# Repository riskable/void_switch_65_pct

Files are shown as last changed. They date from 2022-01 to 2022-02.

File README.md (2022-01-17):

# Void Switch Reference PCB Implementation

A reference implementation of an analog hall effect keyboard (65%) that uses 3D printed Void Switches and a Black Pill (STM32F4x1CEU6) microcontroller board.

__WARNING:__ I haven't had a chance to order and test this yet!  Use at your own risk!  YOU HAVE BEEN WARNED!

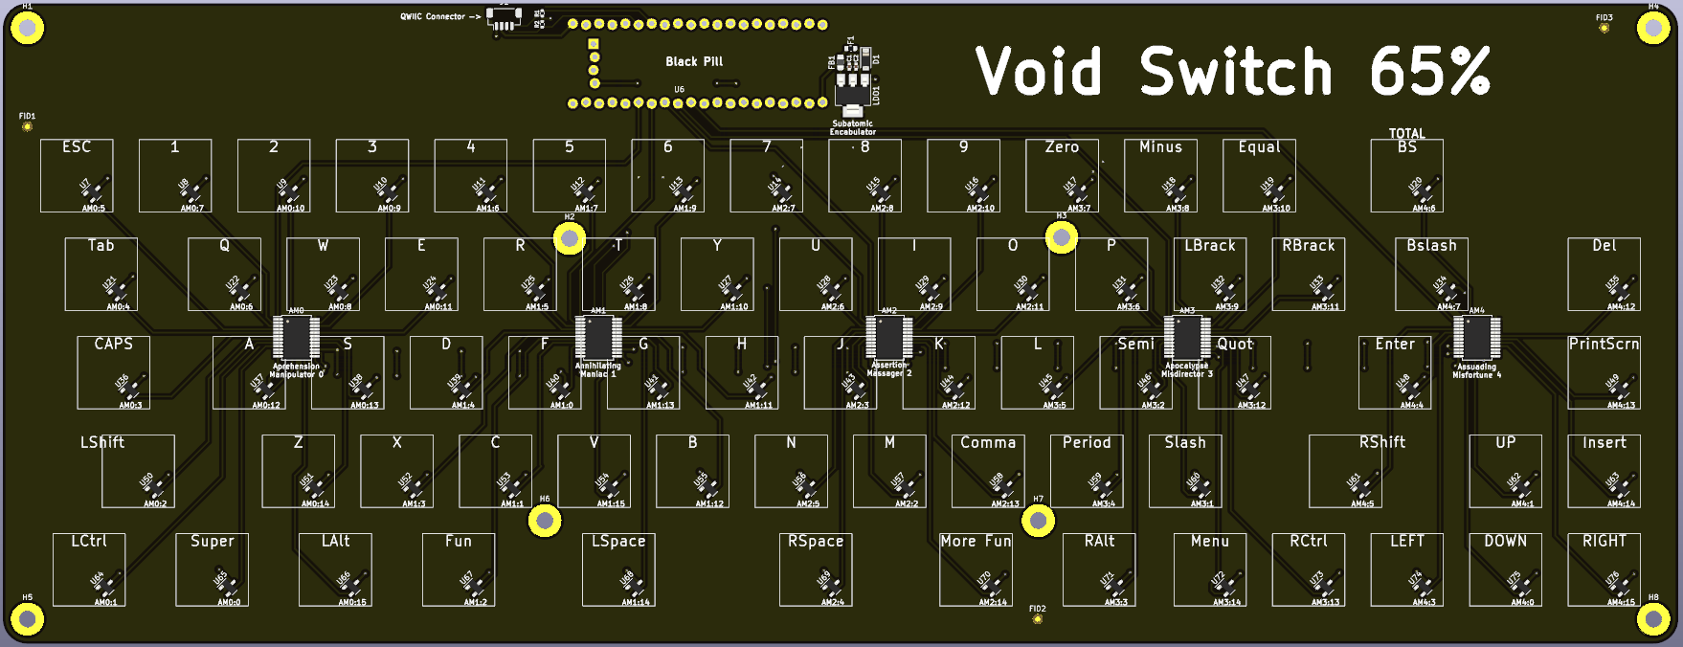
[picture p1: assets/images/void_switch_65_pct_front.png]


Inside this repository is a Kicad 6 project that has everything you need to get started making an analog keyboard PCB that uses 3D printed [Void Switches](https://github.com/riskable/void_switch).  It was made as part of a tutorial that is currently being worked on.  In the mean time--if you know what you're doing--feel to use it as a reference for creating your own analog keyboard PCBs.

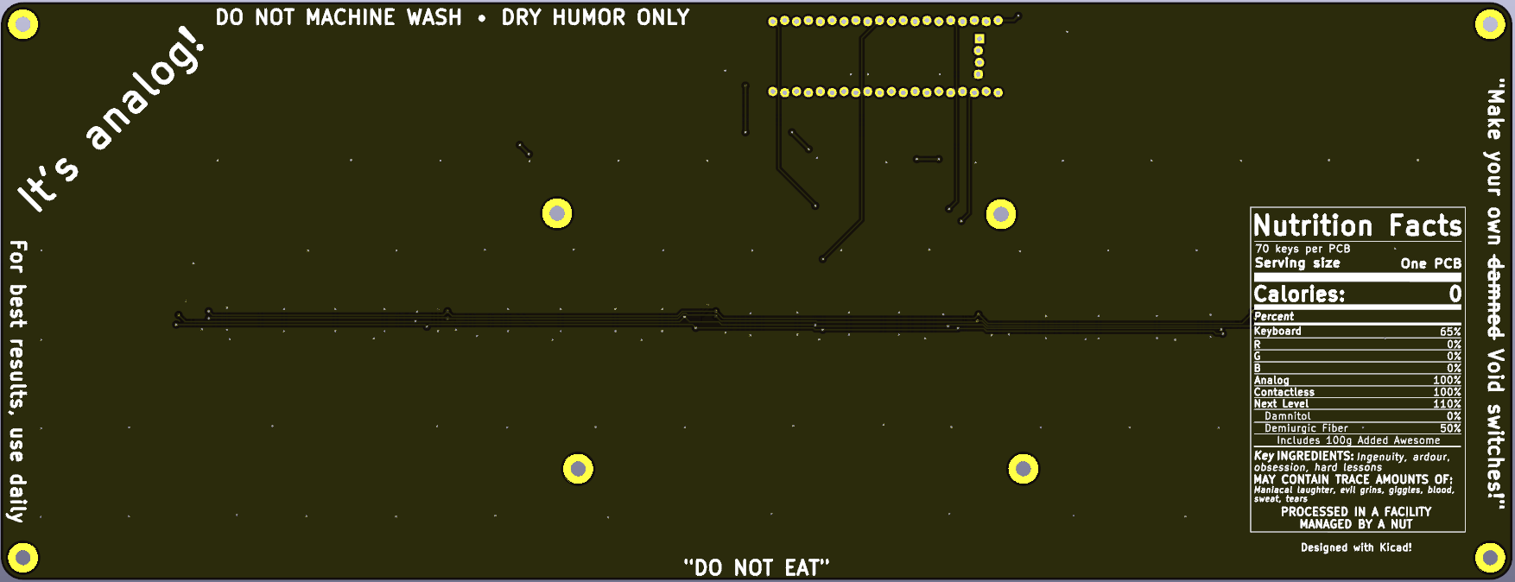
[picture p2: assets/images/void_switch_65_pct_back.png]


# Included footprints and symbols

The [void_switch_kicad](https://github.com/riskable/void_switch_kicad) repository was added as a `git submodule` so don't forget to run `git submodule foreach git pull` from time to time in order to make sure it stays up-to-date.

There's also:

 * `kicad_misc_parts` which for now just includes a single footprint for a vertical QWIIC/4-pin JST connector that happens to be easy to obtain right now (damn you, parts shortage!).
 * `kicad_blackpill` which contains a simple symbol and footprint for the WeAct Studio Black Pill board.  If you're wondering about the staggered pins it's just a neat way to make hand-soldering a bit easier (it holds the headers in place while you solder; so they won't shift around/lean/fall out).

# Tutorial and OpenSCAD case/plate files are coming soon!

Remember folks: This is my hobby, not my full time job =)

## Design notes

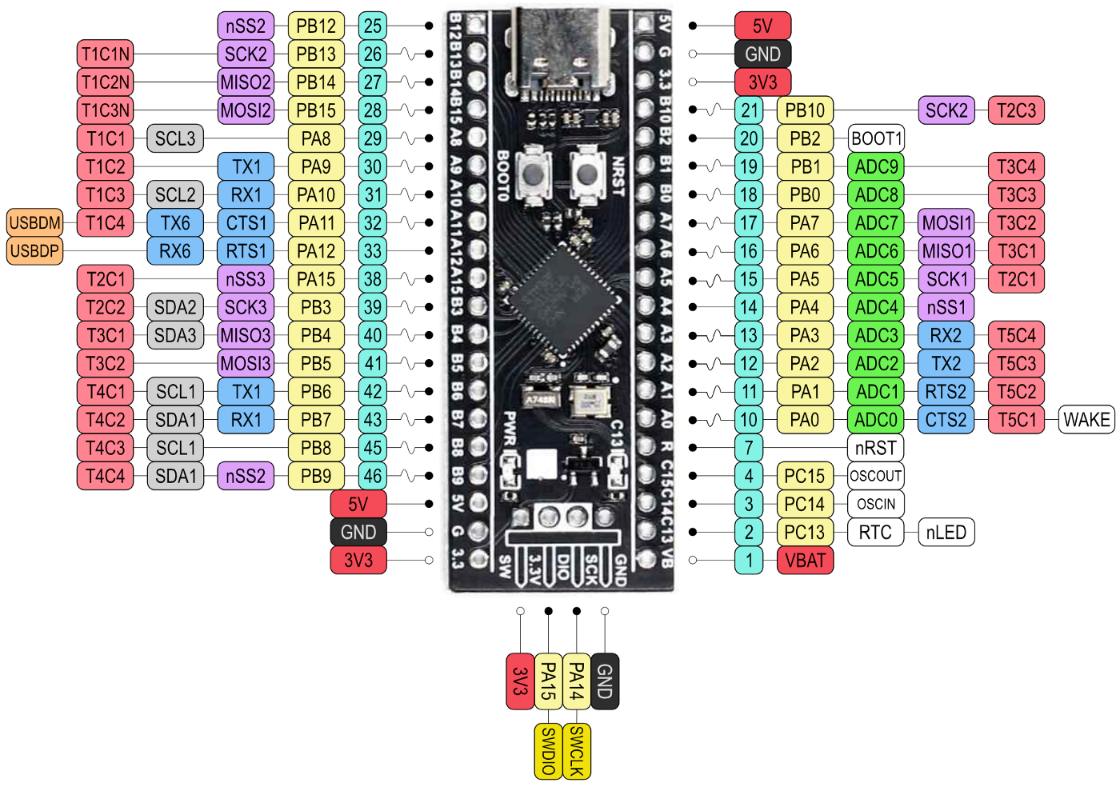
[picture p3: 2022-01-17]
kicad_blackpill/pinout.png

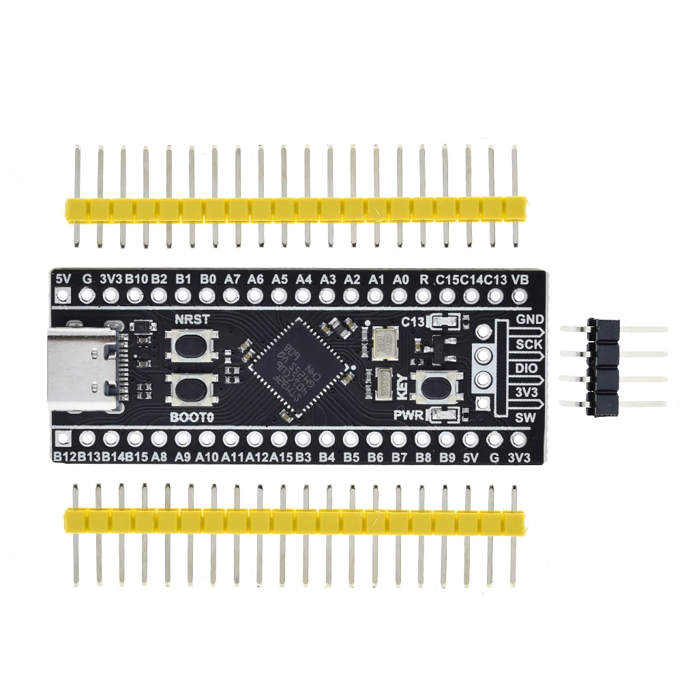
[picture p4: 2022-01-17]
kicad_blackpill/board.jpg

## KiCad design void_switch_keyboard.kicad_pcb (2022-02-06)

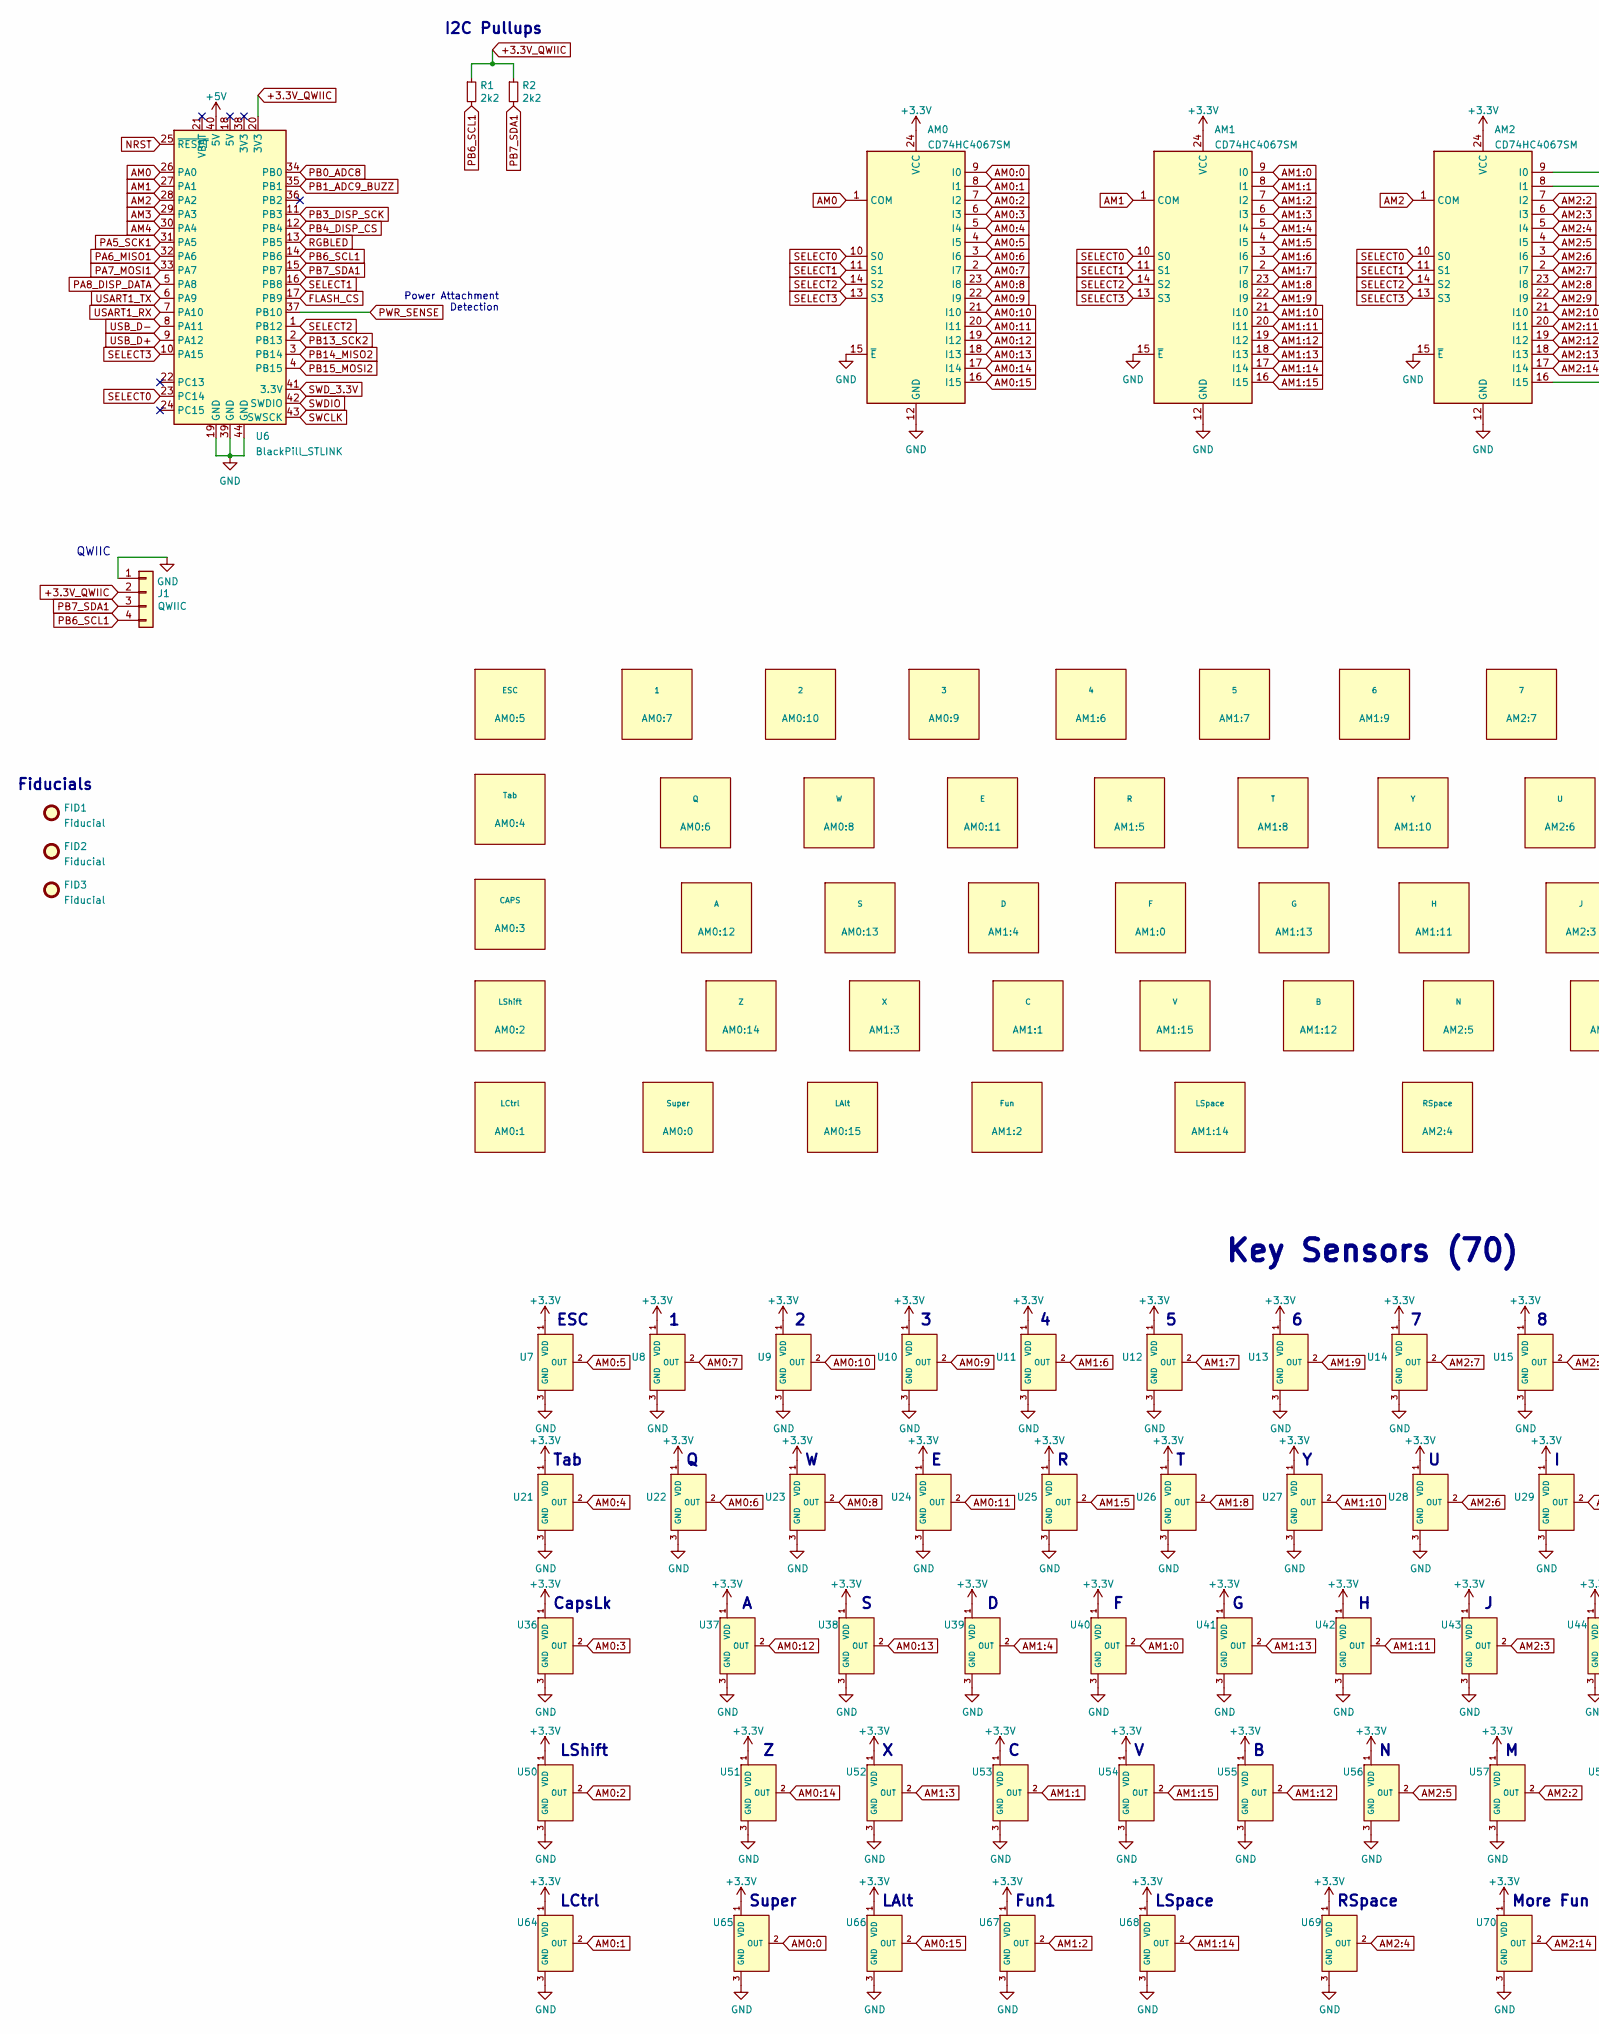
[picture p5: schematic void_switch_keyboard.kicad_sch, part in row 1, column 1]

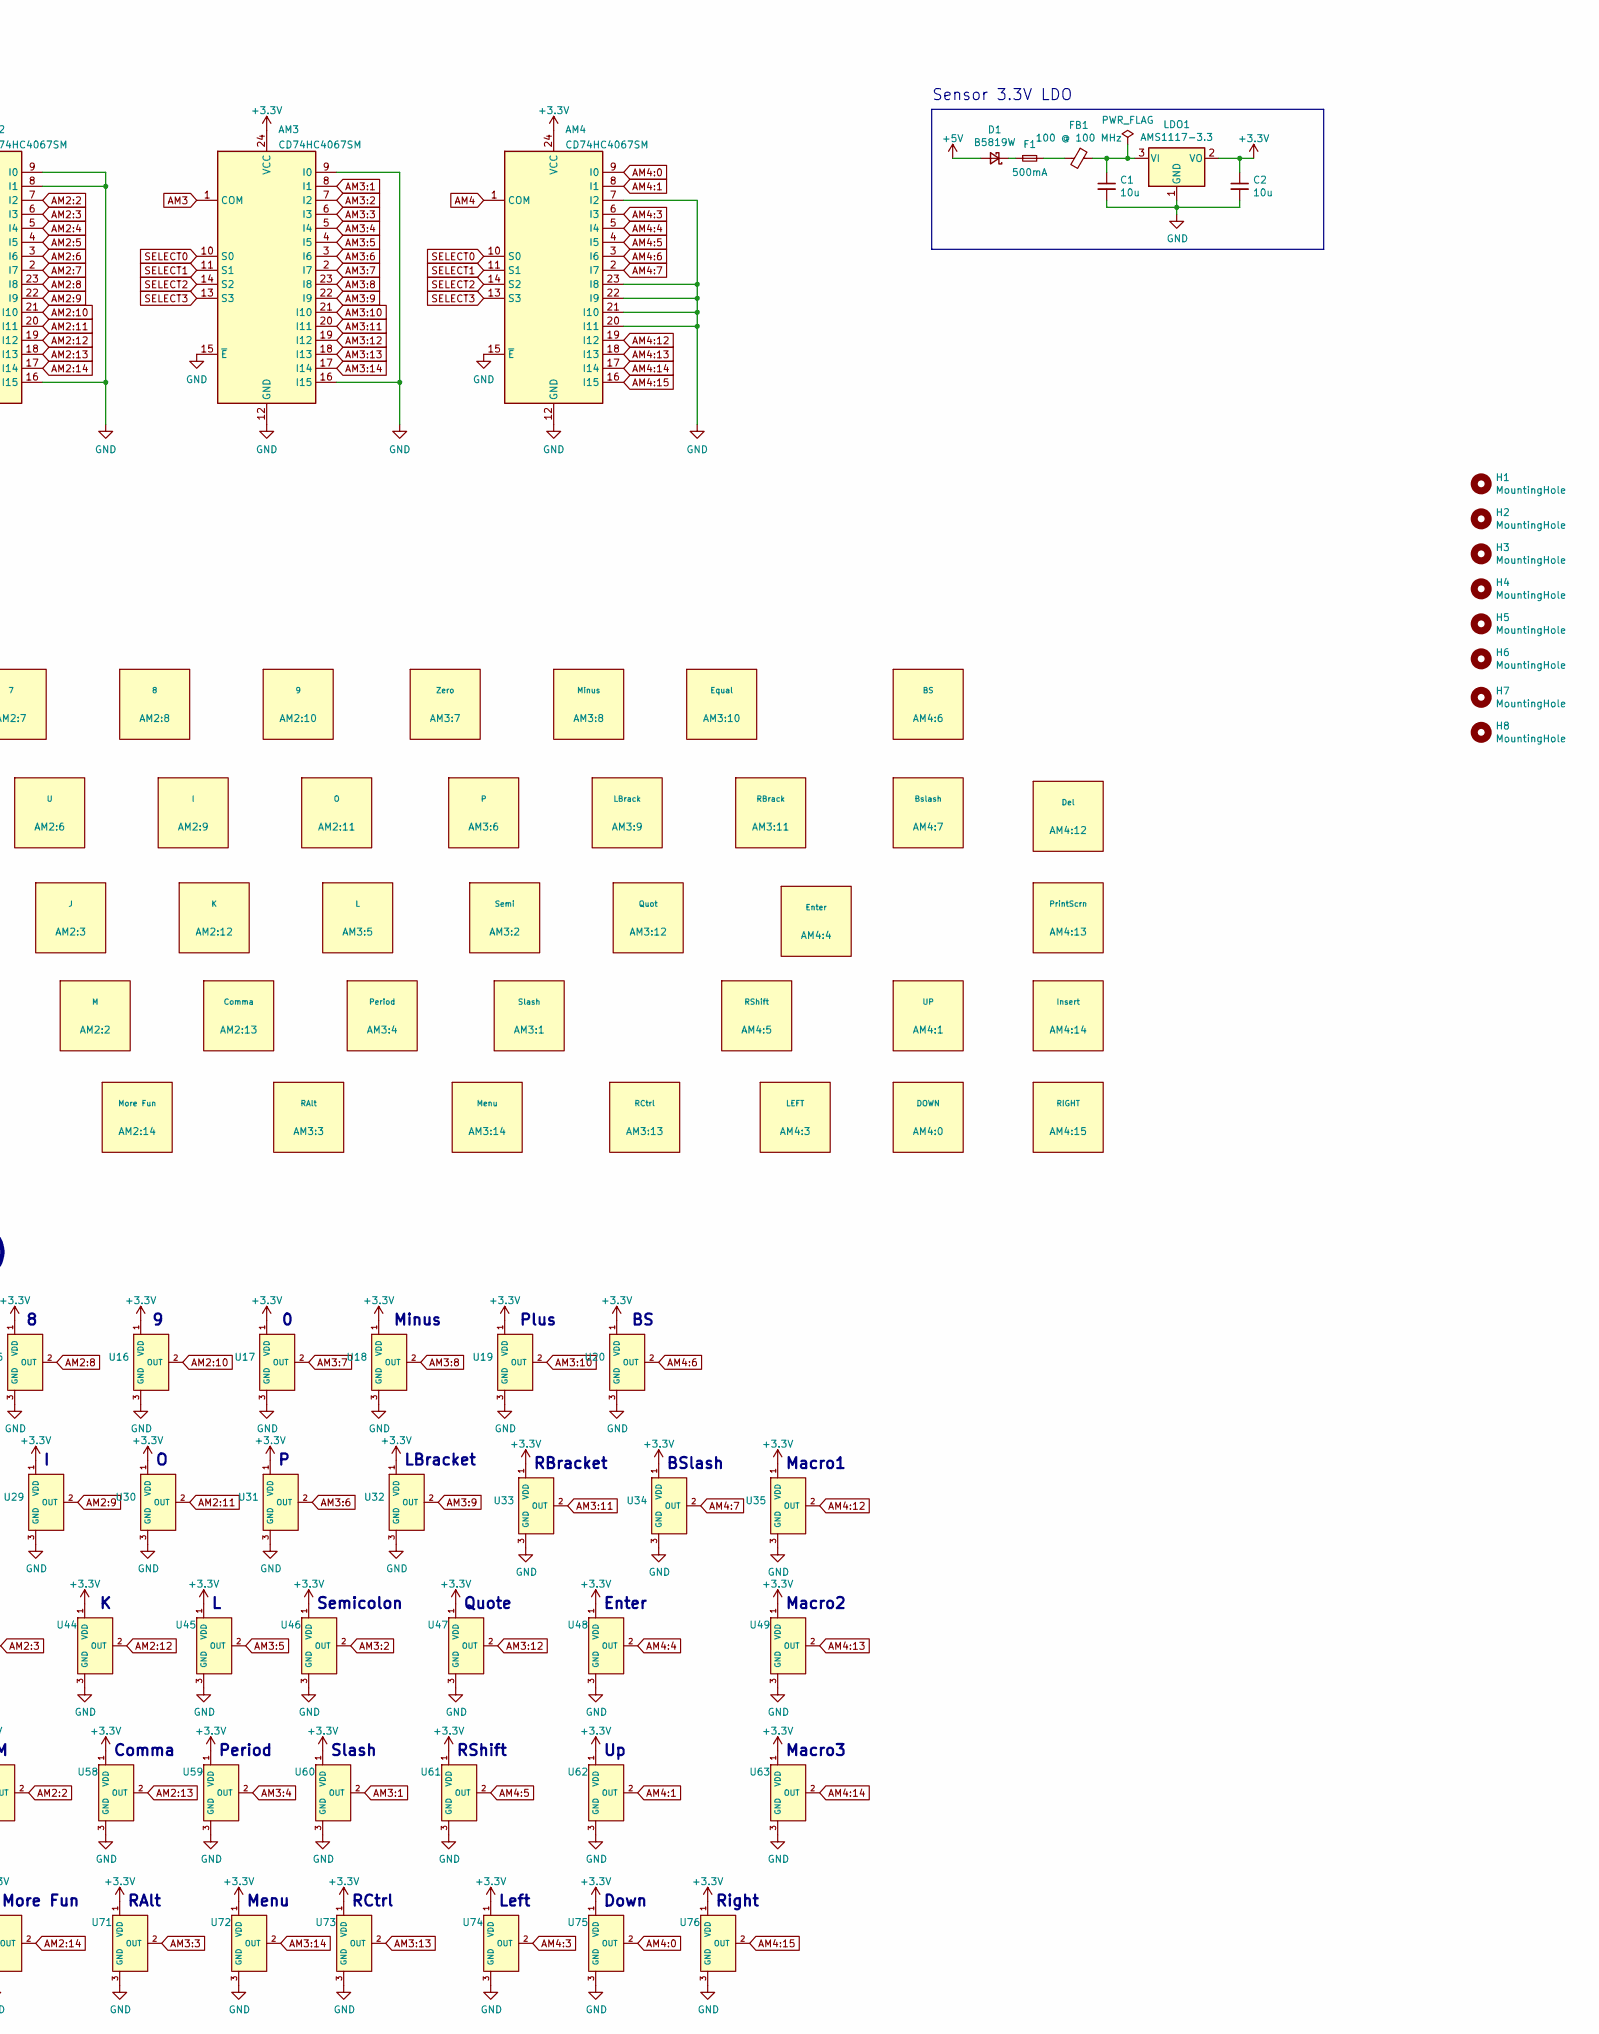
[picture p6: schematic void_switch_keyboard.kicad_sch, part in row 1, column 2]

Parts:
AM0, AM1, AM2, AM3, AM4: CD74HC4067SM; SSOP-24_5.3x8.2mm_P0.65mm
AM0:0: Super; VoidSwitch_1.25u_SMD
AM0:1: LCtrl; VoidSwitch_1.25u_SMD
AM0:2: LShift; VoidSwitch_1u_SMD
AM0:3: CAPS; VoidSwitch_1u_SMD
AM0:4: Tab; VoidSwitch_1u_SMD
AM0:5: ESC; VoidSwitch_1u_SMD
AM0:6: Q; VoidSwitch_1u_SMD
AM0:7: 1; VoidSwitch_1u_SMD
AM0:8: W; VoidSwitch_1u_SMD
AM0:9: 3; VoidSwitch_1u_SMD
AM0:10: 2; VoidSwitch_1u_SMD
AM0:11: E; VoidSwitch_1u_SMD
AM0:12: A; VoidSwitch_1u_SMD
AM0:13: S; VoidSwitch_1u_SMD
AM0:14: Z; VoidSwitch_1u_SMD
AM0:15: LAlt; VoidSwitch_1.25u_SMD
AM1:0: F; VoidSwitch_1u_SMD
AM1:1: C; VoidSwitch_1u_SMD
AM1:2: Fun; VoidSwitch_1.25u_SMD
AM1:3: X; VoidSwitch_1u_SMD
AM1:4: D; VoidSwitch_1u_SMD
AM1:5: R; VoidSwitch_1u_SMD
AM1:6: 4; VoidSwitch_1u_SMD
AM1:7: 5; VoidSwitch_1u_SMD
AM1:8: T; VoidSwitch_1u_SMD
AM1:9: 6; VoidSwitch_1u_SMD
AM1:10: Y; VoidSwitch_1u_SMD
AM1:11: H; VoidSwitch_1u_SMD
AM1:12: B; VoidSwitch_1u_SMD
AM1:13: G; VoidSwitch_1u_SMD
AM1:14: LSpace; VoidSwitch_1u_SMD
AM1:15: V; VoidSwitch_1u_SMD
AM2:2: M; VoidSwitch_1u_SMD
AM2:3: J; VoidSwitch_1u_SMD
AM2:4: RSpace; VoidSwitch_1u_SMD
AM2:5: N; VoidSwitch_1u_SMD
AM2:6: U; VoidSwitch_1u_SMD
AM2:7: 7; VoidSwitch_1u_SMD
AM2:8: 8; VoidSwitch_1u_SMD
AM2:9: I; VoidSwitch_1u_SMD
AM2:10: 9; VoidSwitch_1u_SMD
AM2:11: O; VoidSwitch_1u_SMD
AM2:12: K; VoidSwitch_1u_SMD
AM2:13: Comma; VoidSwitch_1u_SMD
AM2:14: More Fun; VoidSwitch_1.25u_SMD
AM3:1: Slash; VoidSwitch_1u_SMD
AM3:2: Semi; VoidSwitch_1u_SMD
AM3:3: RAlt; VoidSwitch_1.25u_SMD
AM3:4: Period; VoidSwitch_1u_SMD
AM3:5: L; VoidSwitch_1u_SMD
AM3:6: P; VoidSwitch_1u_SMD
AM3:7: Zero; VoidSwitch_1u_SMD
AM3:8: Minus; VoidSwitch_1u_SMD
AM3:9: LBrack; VoidSwitch_1u_SMD
AM3:10: Equal; VoidSwitch_1u_SMD
AM3:11: RBrack; VoidSwitch_1u_SMD
AM3:12: Quot; VoidSwitch_1u_SMD
AM3:13: RCtrl; VoidSwitch_1u_SMD
AM3:14: Menu; VoidSwitch_1u_SMD
AM4:0: DOWN; VoidSwitch_1u_SMD
AM4:1: UP; VoidSwitch_1u_SMD
AM4:3: LEFT; VoidSwitch_1u_SMD
AM4:4: Enter; VoidSwitch_1u_SMD
AM4:5: RShift; VoidSwitch_1u_SMD
AM4:6: BS; VoidSwitch_1u_SMD
AM4:7: Bslash; VoidSwitch_1u_SMD
AM4:12: Del; VoidSwitch_1u_SMD
AM4:13: PrintScrn; VoidSwitch_1u_SMD
AM4:14: Insert; VoidSwitch_1u_SMD
AM4:15: RIGHT; VoidSwitch_1u_SMD
C1, C2: 10u; C_0402_1005Metric; MPN CL05A106MQ5NUNC; LCSC Part C15525
D1: B5819W; D_SOD-123; MPN B5819W; LCSC Part C8598
F1: 500mA; Fuse_0603_1608Metric; LCSC Part C261937
FB1: 100 @ 100 MHz; L_0805_2012Metric; MPN GZ2012D101TF; LCSC Part C1015
FID1, FID2, FID3: Fiducial; Fiducial_1mm_Mask2mm
H1, H2, H3, H4, H5, H6, H7, H8: MountingHole; MountingHole_3.2mm_M3_Pad
J1: QWIIC; JST_SH_BM04B-SRSS-TB_1x04-1MP_P1.00mm_Vertical; LCSC Part C160404
LDO1: AMS1117-3.3; SOT-223-3_TabPin2; MPN AMS1117-3.3; LCSC Part C6186
R1, R2: 2k2; R_0402_1005Metric; MPN 0402WGF2201TCE; LCSC Part C25879
U6: BlackPill_STLINK
U7, U8, U9, U10, U11, U12, U13, U14, U15, U16, U17, U18, U19, U20, U21, U22, U23, U24, U25, U26, U27, U28, U29, U30, U31, U32, U33, U34, U35, U36, U37, U38, U39, U40, U41, U42, U43, U44, U45, U46, U47, U48, U49, U50, U51, U52, U53, U54, U55, U56, U57, U58, U59, U60, U61, U62, U63, U64, U65, U66, U67, U68, U69, U70, U71, U72, U73, U74, U75, U76: GH39FKSW; SOT-23; MPN GH39FKSW; LCSC Part C266230

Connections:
+3.3V_QWIIC: J1.2, R1.1, R2.1, U6.20 (3V3)
+3V3: AM0.24 (VCC), AM1.24 (VCC), AM2.24 (VCC), AM3.24 (VCC), AM4.24 (VCC), C2.1, LDO1.2 (VO), U7.1 (VDD), U8.1 (VDD), U9.1 (VDD), U10.1 (VDD), U11.1 (VDD), U12.1 (VDD), U13.1 (VDD), U14.1 (VDD), U15.1 (VDD), U16.1 (VDD), U17.1 (VDD), U18.1 (VDD), U19.1 (VDD), U20.1 (VDD), U21.1 (VDD), U22.1 (VDD), U23.1 (VDD), U24.1 (VDD), U25.1 (VDD), U26.1 (VDD), U27.1 (VDD), U28.1 (VDD), U29.1 (VDD), U30.1 (VDD), U31.1 (VDD), U32.1 (VDD), U33.1 (VDD), U34.1 (VDD), U35.1 (VDD), U36.1 (VDD), U37.1 (VDD), U38.1 (VDD), U39.1 (VDD), U40.1 (VDD), U41.1 (VDD), U42.1 (VDD), U43.1 (VDD), U44.1 (VDD), U45.1 (VDD), U46.1 (VDD), U47.1 (VDD), U48.1 (VDD), U49.1 (VDD), U50.1 (VDD), U51.1 (VDD), U52.1 (VDD), U53.1 (VDD), U54.1 (VDD), U55.1 (VDD), U56.1 (VDD), U57.1 (VDD), U58.1 (VDD), U59.1 (VDD), U60.1 (VDD), U61.1 (VDD), U62.1 (VDD), U63.1 (VDD), U64.1 (VDD), U65.1 (VDD), U66.1 (VDD), U67.1 (VDD), U68.1 (VDD), U69.1 (VDD), U70.1 (VDD), U71.1 (VDD), U72.1 (VDD), U73.1 (VDD), U74.1 (VDD), U75.1 (VDD), U76.1 (VDD)
+5V: D1.2 (A), U6.40 (5V)
AM0: AM0.1 (COM), U6.26 (PA0)
AM0:0: AM0.9 (I0), U65.2 (OUT)
AM0:1: AM0.8 (I1), U64.2 (OUT)
AM0:2: AM0.7 (I2), U50.2 (OUT)
AM0:3: AM0.6 (I3), U36.2 (OUT)
AM0:4: AM0.5 (I4), U21.2 (OUT)
AM0:5: AM0.4 (I5), U7.2 (OUT)
AM0:6: AM0.3 (I6), U22.2 (OUT)
AM0:7: AM0.2 (I7), U8.2 (OUT)
AM0:8: AM0.23 (I8), U23.2 (OUT)
AM0:9: AM0.22 (I9), U10.2 (OUT)
AM0:10: AM0.21 (I10), U9.2 (OUT)
AM0:11: AM0.20 (I11), U24.2 (OUT)
AM0:12: AM0.19 (I12), U37.2 (OUT)
AM0:13: AM0.18 (I13), U38.2 (OUT)
AM0:14: AM0.17 (I14), U51.2 (OUT)
AM0:15: AM0.16 (I15), U66.2 (OUT)
AM1: AM1.1 (COM), U6.27 (PA1)
AM1:0: AM1.9 (I0), U40.2 (OUT)
AM1:1: AM1.8 (I1), U53.2 (OUT)
AM1:2: AM1.7 (I2), U67.2 (OUT)
AM1:3: AM1.6 (I3), U52.2 (OUT)
AM1:4: AM1.5 (I4), U39.2 (OUT)
AM1:5: AM1.4 (I5), U25.2 (OUT)
AM1:6: AM1.3 (I6), U11.2 (OUT)
AM1:7: AM1.2 (I7), U12.2 (OUT)
AM1:8: AM1.23 (I8), U26.2 (OUT)
AM1:9: AM1.22 (I9), U13.2 (OUT)
AM1:10: AM1.21 (I10), U27.2 (OUT)
AM1:11: AM1.20 (I11), U42.2 (OUT)
AM1:12: AM1.19 (I12), U55.2 (OUT)
AM1:13: AM1.18 (I13), U41.2 (OUT)
AM1:14: AM1.17 (I14), U68.2 (OUT)
AM1:15: AM1.16 (I15), U54.2 (OUT)
AM2: AM2.1 (COM), U6.28 (PA2)
AM2:2: AM2.7 (I2), U57.2 (OUT)
AM2:3: AM2.6 (I3), U43.2 (OUT)
AM2:4: AM2.5 (I4), U69.2 (OUT)
AM2:5: AM2.4 (I5), U56.2 (OUT)
AM2:6: AM2.3 (I6), U28.2 (OUT)
AM2:7: AM2.2 (I7), U14.2 (OUT)
AM2:8: AM2.23 (I8), U15.2 (OUT)
AM2:9: AM2.22 (I9), U29.2 (OUT)
AM2:10: AM2.21 (I10), U16.2 (OUT)
AM2:11: AM2.20 (I11), U30.2 (OUT)
AM2:12: AM2.19 (I12), U44.2 (OUT)
AM2:13: AM2.18 (I13), U58.2 (OUT)
AM2:14: AM2.17 (I14), U70.2 (OUT)
AM3: AM3.1 (COM), U6.29 (PA3)
AM3:1: AM3.8 (I1), U60.2 (OUT)
AM3:2: AM3.7 (I2), U46.2 (OUT)
AM3:3: AM3.6 (I3), U71.2 (OUT)
AM3:4: AM3.5 (I4), U59.2 (OUT)
AM3:5: AM3.4 (I5), U45.2 (OUT)
AM3:6: AM3.3 (I6), U31.2 (OUT)
AM3:7: AM3.2 (I7), U17.2 (OUT)
AM3:8: AM3.23 (I8), U18.2 (OUT)
AM3:9: AM3.22 (I9), U32.2 (OUT)
AM3:10: AM3.21 (I10), U19.2 (OUT)
AM3:11: AM3.20 (I11), U33.2 (OUT)
AM3:12: AM3.19 (I12), U47.2 (OUT)
AM3:13: AM3.18 (I13), U73.2 (OUT)
AM3:14: AM3.17 (I14), U72.2 (OUT)
AM4: AM4.1 (COM), U6.30 (PA4)
AM4:0: AM4.9 (I0), U75.2 (OUT)
AM4:1: AM4.8 (I1), U62.2 (OUT)
AM4:3: AM4.6 (I3), U74.2 (OUT)
AM4:4: AM4.5 (I4), U48.2 (OUT)
AM4:5: AM4.4 (I5), U61.2 (OUT)
AM4:6: AM4.3 (I6), U20.2 (OUT)
AM4:7: AM4.2 (I7), U34.2 (OUT)
AM4:12: AM4.19 (I12), U35.2 (OUT)
AM4:13: AM4.18 (I13), U49.2 (OUT)
AM4:14: AM4.17 (I14), U63.2 (OUT)
AM4:15: AM4.16 (I15), U76.2 (OUT)
FLASH_CS: U6.17 (PB9)
GND: AM0.12 (GND), AM0.15 (~E), AM1.12 (GND), AM1.15 (~E), AM2.8 (I1), AM2.9 (I0), AM2.12 (GND), AM2.15 (~E), AM2.16 (I15), AM3.9 (I0), AM3.12 (GND), AM3.15 (~E), AM3.16 (I15), AM4.7 (I2), AM4.12 (GND), AM4.15 (~E), AM4.20 (I11), AM4.21 (I10), AM4.22 (I9), AM4.23 (I8), C1.2, C2.2, J1.1, LDO1.1 (GND), U6.19 (GND), U6.39 (GND), U6.44 (GND), U7.3 (GND), U8.3 (GND), U9.3 (GND), U10.3 (GND), U11.3 (GND), U12.3 (GND), U13.3 (GND), U14.3 (GND), U15.3 (GND), U16.3 (GND), U17.3 (GND), U18.3 (GND), U19.3 (GND), U20.3 (GND), U21.3 (GND), U22.3 (GND), U23.3 (GND), U24.3 (GND), U25.3 (GND), U26.3 (GND), U27.3 (GND), U28.3 (GND), U29.3 (GND), U30.3 (GND), U31.3 (GND), U32.3 (GND), U33.3 (GND), U34.3 (GND), U35.3 (GND), U36.3 (GND), U37.3 (GND), U38.3 (GND), U39.3 (GND), U40.3 (GND), U41.3 (GND), U42.3 (GND), U43.3 (GND), U44.3 (GND), U45.3 (GND), U46.3 (GND), U47.3 (GND), U48.3 (GND), U49.3 (GND), U50.3 (GND), U51.3 (GND), U52.3 (GND), U53.3 (GND), U54.3 (GND), U55.3 (GND), U56.3 (GND), U57.3 (GND), U58.3 (GND), U59.3 (GND), U60.3 (GND), U61.3 (GND), U62.3 (GND), U63.3 (GND), U64.3 (GND), U65.3 (GND), U66.3 (GND), U67.3 (GND), U68.3 (GND), U69.3 (GND), U70.3 (GND), U71.3 (GND), U72.3 (GND), U73.3 (GND), U74.3 (GND), U75.3 (GND), U76.3 (GND)
NRST: U6.25 (~RESET)
unnamed: C1.1, FB1.1, LDO1.3 (VI)
unnamed: D1.1 (K), F1.1
unnamed: F1.2, FB1.2
PA5_SCK1: U6.31 (PA5)
PA6_MISO1: U6.32 (PA6)
PA7_MOSI1: U6.33 (PA7)
PA8_DISP_DATA: U6.5 (PA8)
PB0_ADC8: U6.34 (PB0)
PB1_ADC9_BUZZ: U6.35 (PB1)
PB3_DISP_SCK: U6.11 (PB3)
PB4_DISP_CS: U6.12 (PB4)
PB6_SCL1: J1.4, R1.2, U6.14 (PB6)
PB7_SDA1: J1.3, R2.2, U6.15 (PB7)
PB13_SCK2: U6.2 (PB13)
PB14_MISO2: U6.3 (PB14)
PB15_MOSI2: U6.4 (PB15)
PWR_SENSE: U6.37 (PB10)
RGBLED: U6.13 (PB5)
SELECT0: AM0.10 (S0), AM1.10 (S0), AM2.10 (S0), AM3.10 (S0), AM4.10 (S0), U6.23 (PC14)
SELECT1: AM0.11 (S1), AM1.11 (S1), AM2.11 (S1), AM3.11 (S1), AM4.11 (S1), U6.16 (PB8)
SELECT2: AM0.14 (S2), AM1.14 (S2), AM2.14 (S2), AM3.14 (S2), AM4.14 (S2), U6.1 (PB12)
SELECT3: AM0.13 (S3), AM1.13 (S3), AM2.13 (S3), AM3.13 (S3), AM4.13 (S3), U6.10 (PA15)
SWCLK: U6.43 (SWSCK)
SWDIO: U6.42 (SWDIO)
SWD_3.3V: U6.41 (3.3V)
USART1_RX: U6.7 (PA10)
USART1_TX: U6.6 (PA9)
USB_D+: U6.9 (PA12)
USB_D-: U6.8 (PA11)

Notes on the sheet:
LAlt
Plus
RShift
LShift
RAlt
RSpace
RCtrl
CapsLk
More Fun
Tab
Down
Macro2
Semicolon
Comma
Enter
Super
RBracket
Right
BSlash
LCtrl
Power Attachment Detection
QWIIC
Fiducials
Minus
LSpace
Left
Slash
Key Sensors (70)
Fun1
Macro1
Macro3
Quote
Period
Menu
I2C Pullups
LBracket
Sensor 3.3V LDO
ESC

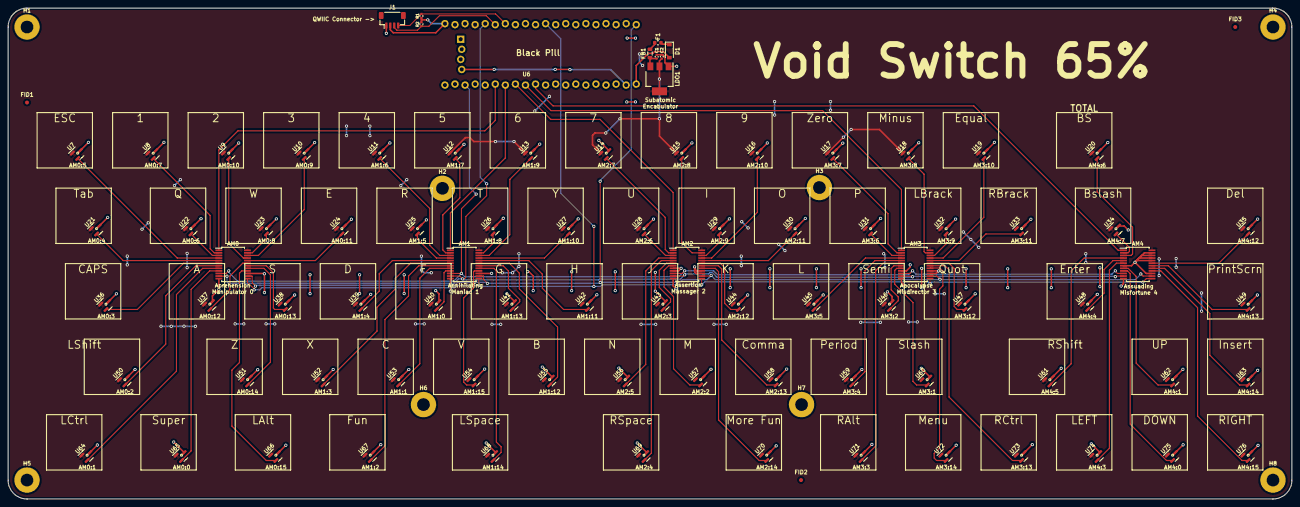
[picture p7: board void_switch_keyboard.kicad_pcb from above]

Board: 2 copper layers, 323.9 x 123.8 mm, 167 parts (1 on the bottom side), 88 nets.

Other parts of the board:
QR*****: https://github.com/riskable/void_switch; VoidSwitch_Repo_QR_0.5mm

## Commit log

2022-01-17 Initial commit.
    [void_switch_keyboard.kicad_pcb, void_switch_keyboard.kicad_sch]
2022-01-17 Added warning to the README about how I haven't had a chance to order/test this board yet.
2022-01-20 Updated silkscreen and fixed the analog multiplexer references so they're AM0-AM4 instead of U1-U5.
    [void_switch_keyboard.kicad_pcb, void_switch_keyboard.kicad_sch]
2022-01-20 Fixed a few minor issues with the silkscreen and added the void_switch repo QR code to the back.
    [void_switch_keyboard.kicad_pcb]
2022-01-24 Fixed the 1.25U keys having 1U footprints.
    [void_switch_keyboard.kicad_pcb, void_switch_keyboard.kicad_sch]
2022-01-24 Fixed AM0:0 and AM0:1 being left floating. They're now connected to ground as they should be (because they're unused).
    [void_switch_keyboard.kicad_pcb, void_switch_keyboard.kicad_sch]
2022-02-06 Fixed a MUX pins that was left floating and added a bit of 3.3V and GND stitching to shorten the power/ground path here and there.
    [void_switch_keyboard.kicad_pcb, void_switch_keyboard.kicad_sch]
